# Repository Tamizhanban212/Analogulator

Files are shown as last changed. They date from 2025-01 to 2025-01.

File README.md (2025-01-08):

# Analogulator

In an era dominated by digital computation, analog computing remains relevant for specific applications that require real-time processing, low power consumption, and continuous data handling. Unlike digital calculators that rely on discrete logic and binary arithmetic, analog calculators use continuous voltage or current levels to represent data, enabling faster and more efficient computations for certain tasks.

This project, "Analog Calculator," aims to design a calculator using only analog components (e.g., op-amps, MOSFETs, resistors, capacitors) to perform mathematical operations such as addition, subtraction, multiplication, division, and advanced functions like integration and differentiation. By leveraging analog circuits, this project explores a simpler, more efficient approach to computations in specific real-world scenarios.

Hence, we have designed PCB for the analog calculator inside a 11 cm x 11 cm frame and you can see the final product shown below.

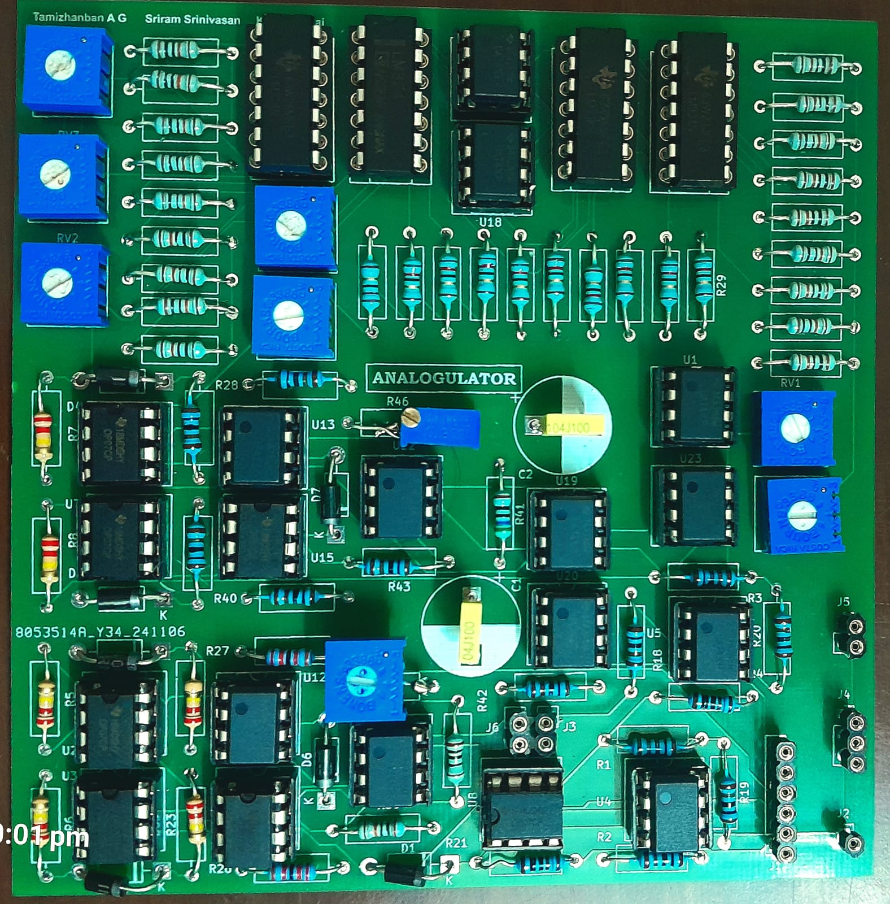
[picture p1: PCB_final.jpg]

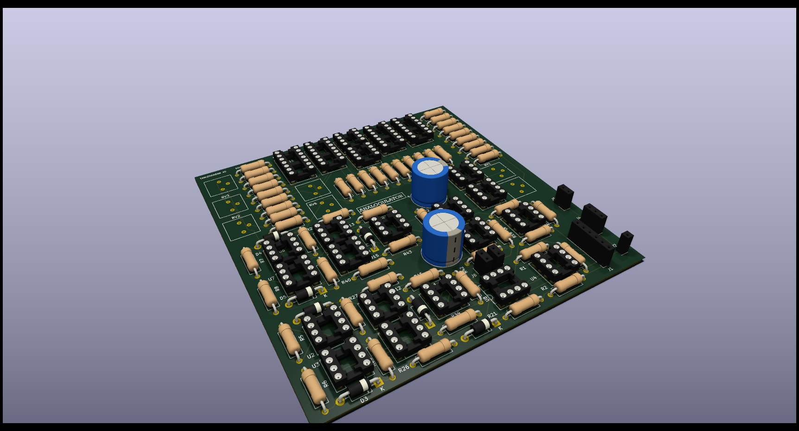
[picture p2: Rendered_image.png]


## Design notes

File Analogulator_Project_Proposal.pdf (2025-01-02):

Analog and Mixed Signal Circuits | Analogulator - Project Proposal

# Analog and Mixed Signal Circuits

### Project Proposal

Analogulator: Redefining Calculations with an Analog Twist

## Introduction

In an era dominated by digital computation, analog computing remains relevant for specific applications that require real-time processing, low power consumption, and continuous data handling. Unlike digital calculators that rely on discrete logic and binary arithmetic, analog calculators use continuous voltage or current levels to represent data, enabling faster and more efficient computations for certain tasks. This project, "Analog Calculator," aims to design a calculator using only analog components (e.g., op-amps, MOSFETs, resistors, capacitors) to perform mathematical operations such as addition, subtraction, multiplication, division, and advanced functions like integration and differentiation. In fact, operational amplifiers originally got its name due to their ability to perform arithmetic operations. Thus, by leveraging analog circuits, this project explores a simpler, more efficient approach to computations in specific real-world scenarios.

## Problem Statement

The renewed interest in analog computing highlights its significance in contemporary technology, particularly for tasks that demand intensive processing such as signal processing, image processing and waveform generation. A key limitation of digital computing lies in its time complexity and power consumption when handling non-discrete calculations such as integration and differentiation. While digital systems offer precise calculations, many applications prioritize speed and low power consumption over extreme precision, where accuracy to 15 decimal places is unnecessary.

Analog computing excels in solving differential equations and generating waveforms—tasks that are inherently challenging for digital systems. This capability is driving advancements in hybrid architectures, enhancing domains like artificial intelligence, embedded systems, and control systems, where fast and energy-efficient computations are vital.

[1] Leading integrated circuit manufacturers are adopting similar strategies, using analog front ends to capitalize on their speed, followed by digital processing for improved accuracy. In successive approximation analog-to-digital converters (ADCs), for instance, reaching a solution typically requires multiple steps. However, by starting with an approximate value provided by the analog front end, the number of steps— and thus computation time and power consumption—can be significantly reduced.
| [1]

## Proposed Approach

### Overview of Approach

The proposed approach involves designing an analog calculator using only analog components like op-amps, MOSFETs, resistors, and capacitors. The calculator will perform a range of mathematical operations, from basic arithmetic (addition, subtraction, multiplication, division and roots) to advanced functions (integration and differentiation). The system will use voltage-based inputs to select operands and operations and employ analog storage techniques for intermediate results. The output will be displayed using LEDs in case of simple operations and an oscilloscope for integration and differentiation. Each component of the system will be built as a modular block, tested independently, and integrated into a cohesive unit.

### Components and Blocks

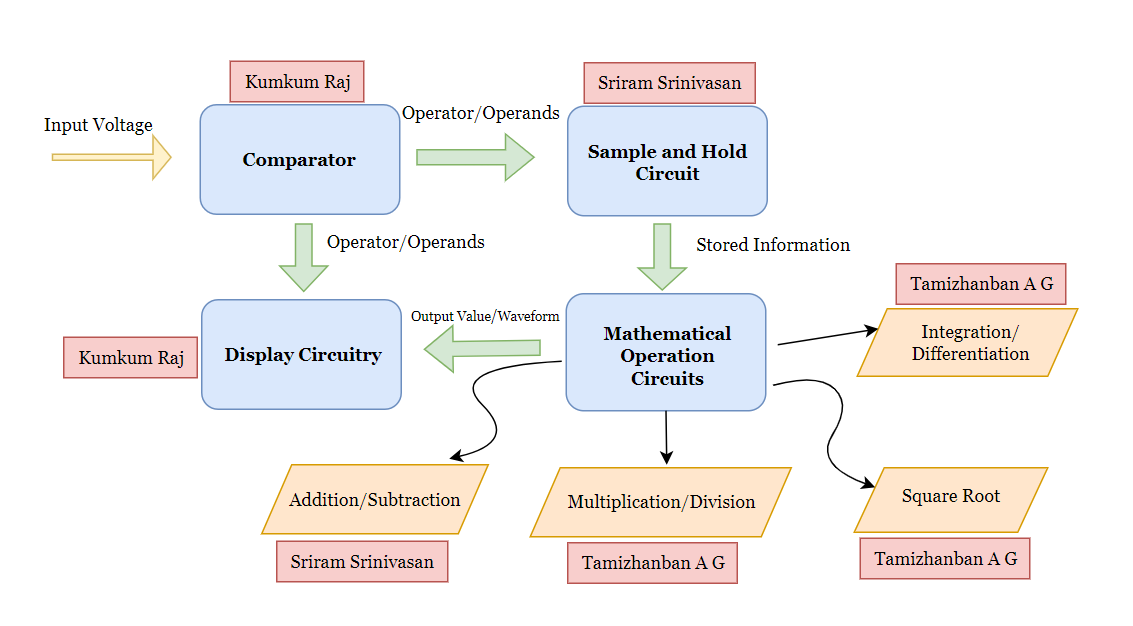
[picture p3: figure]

### 1. Input Signal Selection: AC or DC Voltage?

For this project, a DC input voltage is the most suitable choice. The objective is to vary the input signal in real-time and observe the corresponding number on an array of LEDs. Using a DC signal allows each voltage level to be mapped directly to a specific digit without the complexities associated with AC signals, such as synchronization with the waveform's phase or frequency. But in the case of integration and differentiation, any signal can be given as input to get a waveform in the output.

### 2. Comparator - Voltage to Digit/Operator Conversion

Multiple window comparator circuits, built using ICs like the LM393 or op-amps such as the LM741 or LM358, can be used to compare the input voltage against predefined reference voltages corresponding to different digits or operators (e.g., 0-1V for "0", 1-2V for "1", etc.). Each comparator triggers when the input voltage falls within its specific range, converting the analog voltage to a digit or an operator.

### 3. Sample and Hold Circuits with Push Button

Sample and Hold (S/H) circuits capture and maintain voltages for operands and operators. The input voltage can be adjusted to select a digit or operator shown by LEDs, then press a push button to store this voltage via a

MOSFET switch. Releasing the button isolates the capacitor, and an op-amp buffer stabilizes the voltage. Three S/H circuits store Operand 1, Operator, and Operand 2 until needed. [2]

### 4. Analog Circuits for Mathematical Operations

- Addition/Subtraction: Operational amplifiers (op-amps) like the LM741 or TL081 can be configured as summing amplifiers for addition and differential amplifiers for subtraction.
- Multiplication/Division: Analog circuits can be built using multipliers ICs such as the AD633. This IC can handle both multiplication and division.
- Square Root: A possible approach would be to use an analog multiplier (MC1495 or AD633) as a squaring circuit, in the feedback loop of an op-amp. [3]
- Integration/Differentiation: Achieved with integrator/differentiator circuits using op-amps like the LM324 or TL081 and carefully chosen resistors and capacitors.

### 5. Display Circuitry Using LEDs and Oscilloscope

For the basic operations (addition, subtraction, multiplication, division), LEDs can be used to display the digits and operators based on the comparator applied on the voltage. For integration and differentiation, an oscilloscope displays the output waveform, showing changes over time. LCDs may be used for clearer representation if needed.

## Advantages of the Proposed Approach

- Low Power Consumption: By leveraging analog components, the proposed solution consumes significantly less power compared to digital counterparts, making it suitable for battery-operated or lowpower applications.
- Real-Time Computation: Analog circuits provide near-instantaneous responses due to their continuous nature, which is beneficial for applications requiring real-time processing without the delay of digital conversions.
- Reduced Complexity and Cost: Analog circuits can perform complex operations with fewer components and simpler designs compared to digital circuits that require complex processing units and memory.
- Elimination of Digital Noise: The analog approach is inherently less prone to digital noise and quantization errors, which enhances accuracy in certain contexts.

## References

[1] R. Elliott, “Analogue electronics maths functions,” Elliott Sound Products. [Online]. Available: https://sound-au.com/articles/maths-functions.htm#intro.

[2] “Sample and Hold Circuit,” GeeksforGeeks. [Online]. Available: https://www.geeksforgeeks.org/sampleand-hold-circuit/. (https://www.geeksforgeeks.org/sample-and-hold-circuit/)
[3] M. Angelo, "Extracting the square root of a voltage," Electronics Stack Exchange, https://electronics.stackexchange.com/questions/78294/extracting-the-square-root-of-a-voltage

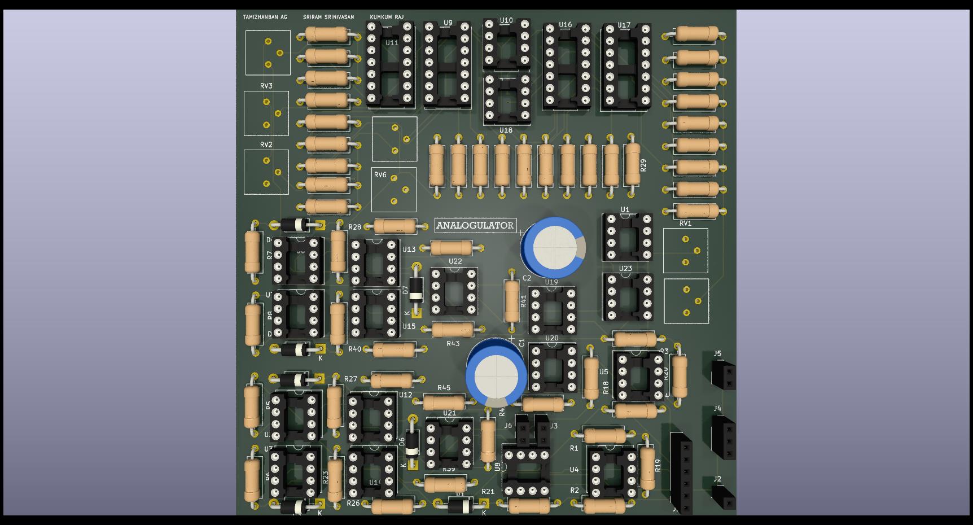
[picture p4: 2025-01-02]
analogulator.jpg

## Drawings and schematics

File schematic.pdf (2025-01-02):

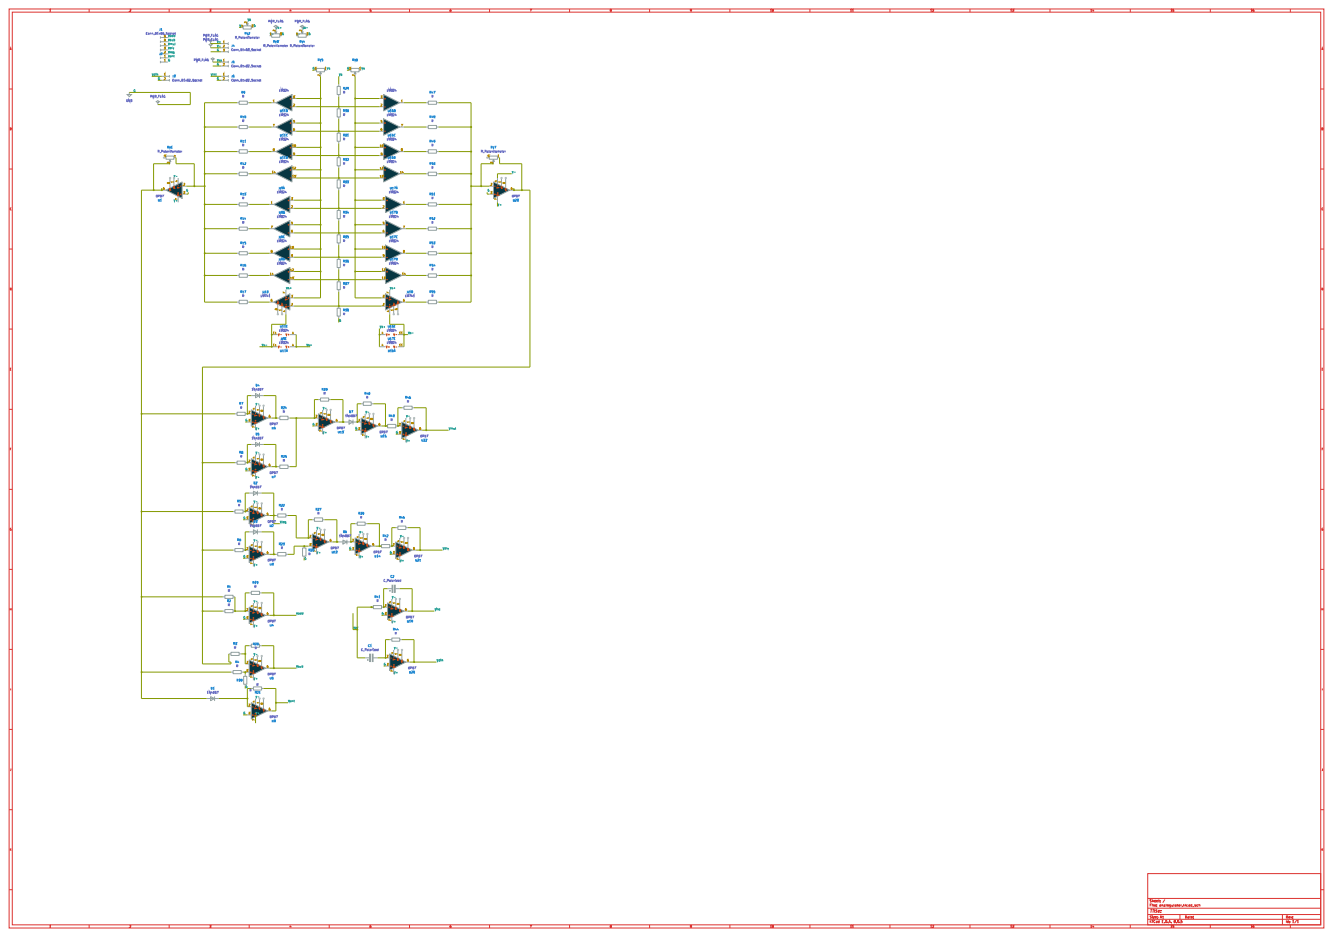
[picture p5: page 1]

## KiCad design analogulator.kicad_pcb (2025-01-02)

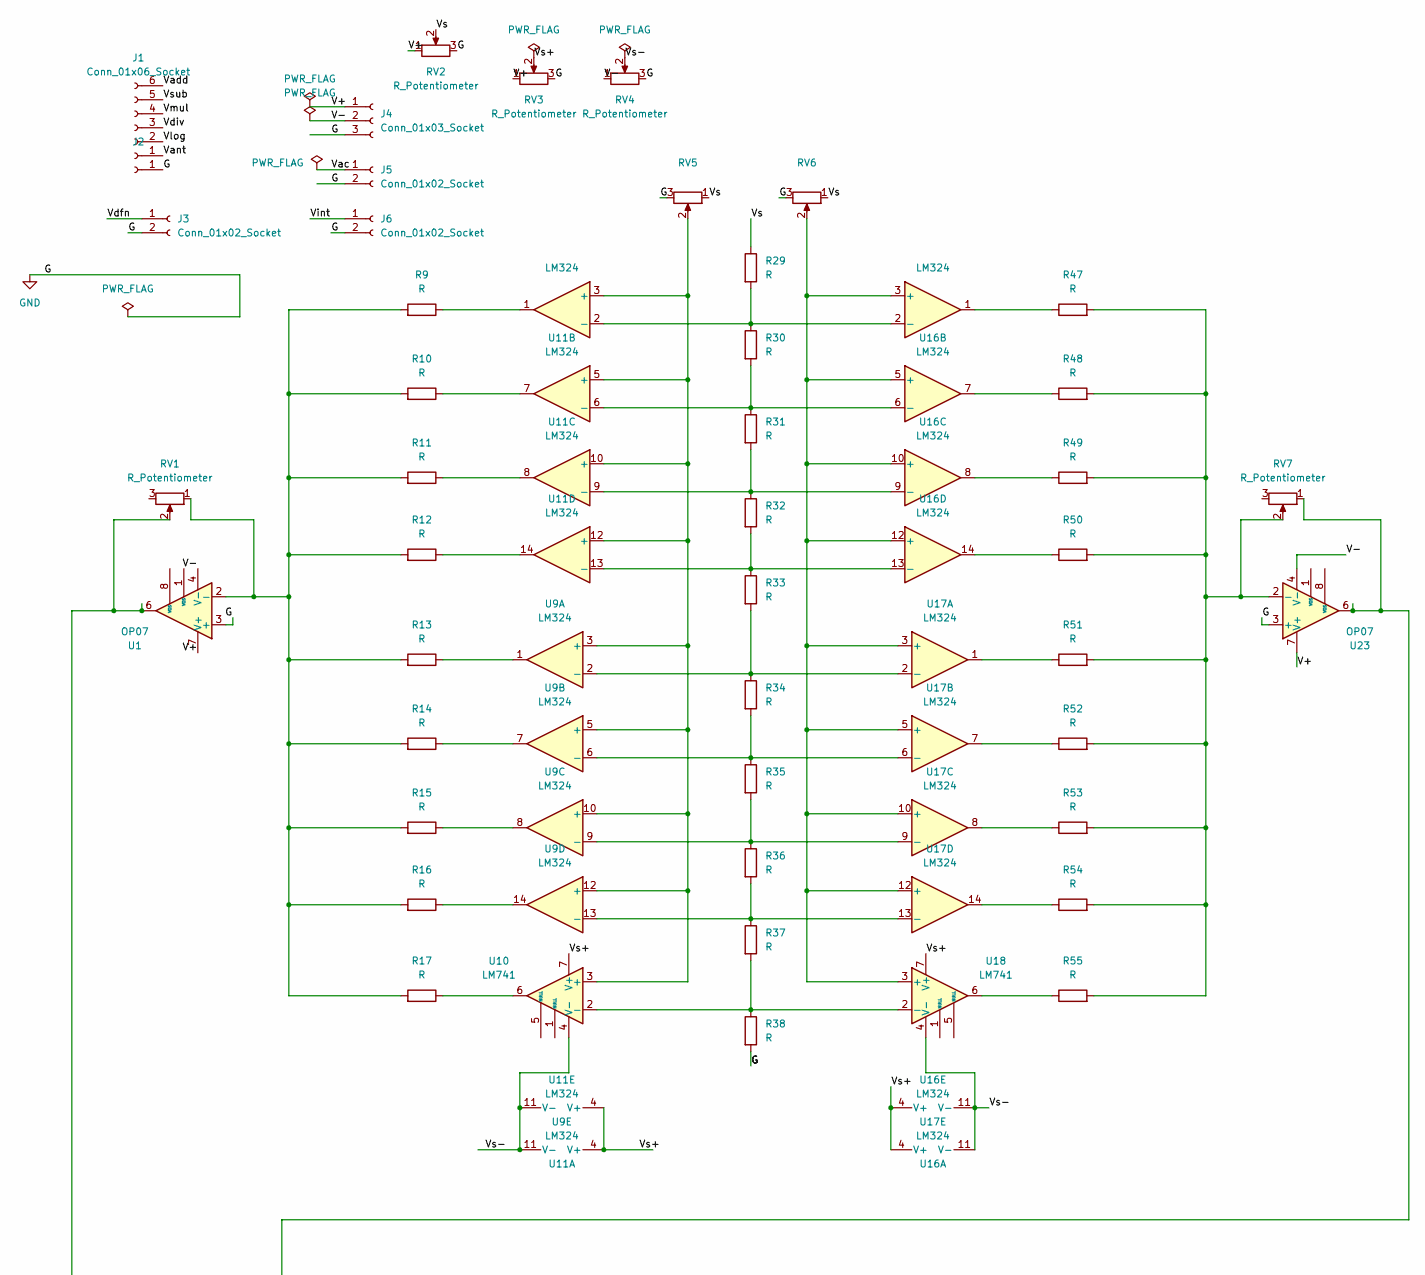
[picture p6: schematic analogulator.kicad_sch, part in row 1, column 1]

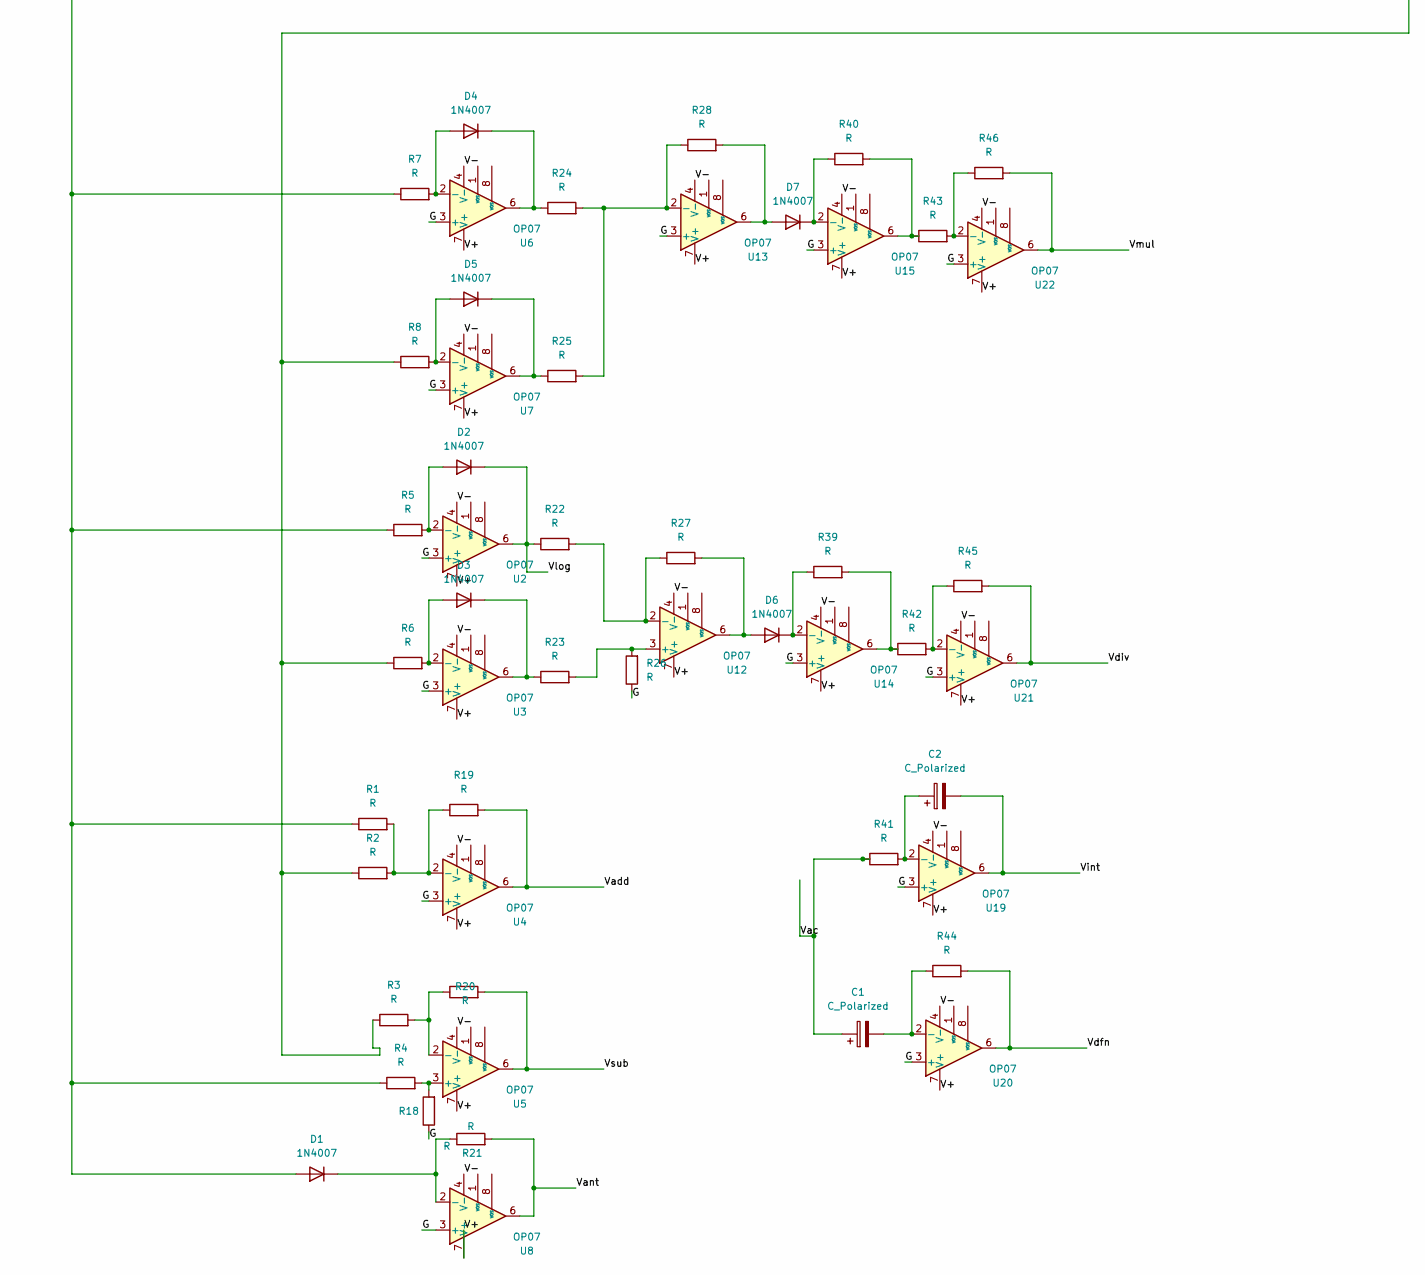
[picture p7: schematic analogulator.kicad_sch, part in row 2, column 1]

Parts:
C1, C2: C_Polarized; CP_Radial_D12.5mm_P7.50mm
D1, D2, D3, D4, D5, D6, D7: 1N4007; D_DO-41_SOD81_P10.16mm_Horizontal
J1: Conn_01x06_Socket; PinSocket_1x06_P2.54mm_Vertical
J2: Conn_01x01_Socket; PinSocket_1x01_P2.54mm_Vertical
J3, J5, J6: Conn_01x02_Socket; PinSocket_1x02_P2.54mm_Vertical
J4: Conn_01x03_Socket; PinSocket_1x03_P2.54mm_Horizontal
R1, R2, R3, R4, R5, R6, R7, R8, R9, R10, R11, R12, R13, R14, R15, R16, R17, R18, R19, R20, R21, R22, R23, R24, R25, R26, R27, R28, R29, R30, R31, R32, R33, R34, R35, R36, R37, R38, R39, R40, R41, R42, R43, R44, R45, R46, R47, R48, R49, R50, R51, R52, R53, R54, R55: R; R_Axial_DIN0309_L9.0mm_D3.2mm_P12.70mm_Horizontal
RV1, RV2, RV3, RV4, RV5, RV6, RV7: R_Potentiometer; Potentiometer_Bourns_3386P_Vertical
U1, U2, U3, U4, U5, U6, U7, U8, U12, U13, U14, U15, U19, U20, U21, U22, U23: OP07; DIP-8_W7.62mm_Socket
U9, U11, U16, U17: LM324; DIP-14_W7.62mm_Socket
U10, U18: LM741; DIP-8_W7.62mm_Socket

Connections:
/V+: J4.1, RV2.1, RV3.1, U1.7 (V+), U2.7 (V+), U3.7 (V+), U4.7 (V+), U5.7 (V+), U6.7 (V+), U7.7 (V+), U8.7 (V+), U12.7 (V+), U13.7 (V+), U14.7 (V+), U15.7 (V+), U19.7 (V+), U20.7 (V+), U21.7 (V+), U22.7 (V+), U23.7 (V+)
/V-: J4.2, RV4.1, U1.4 (V-), U2.4 (V-), U3.4 (V-), U4.4 (V-), U5.4 (V-), U6.4 (V-), U7.4 (V-), U8.4 (V-), U12.4 (V-), U13.4 (V-), U14.4 (V-), U15.4 (V-), U19.4 (V-), U20.4 (V-), U21.4 (V-), U22.4 (V-), U23.4 (V-)
/Vac: C1.1, J5.1, R41.1
/Vadd: J1.6, R19.2, U4.6
/Vant: J1.1, R21.2, U8.6
/Vdfn: J3.1, R44.2, U20.6
/Vdiv: J1.3, R45.2, U21.6
/Vint: C2.2, J6.1, U19.6
/Vlog: D2.1 (K), J1.2, R22.1, U2.6
/Vmul: J1.4, R46.2, U22.6
/Vs: R29.1, RV2.2, RV5.1, RV6.1
/Vs+: RV3.2, U9.4 (V+), U10.7 (V+), U11.4 (V+), U16.4 (V+), U17.4 (V+), U18.7 (V+)
/Vs-: RV4.2, U9.11 (V-), U10.4 (V-), U11.11 (V-), U16.11 (V-), U17.11 (V-), U18.4 (V-)
/Vsub: J1.5, R20.2, U5.6
GND: J2.1, J3.2, J4.3, J5.2, J6.2, R18.1, R26.1, R38.2, RV2.3, RV3.3, RV4.3, RV5.3, RV6.3, U1.3 (+), U2.3 (+), U3.3 (+), U4.3 (+), U6.3 (+), U7.3 (+), U8.3 (+), U13.3 (+), U14.3 (+), U15.3 (+), U19.3 (+), U20.3 (+), U21.3 (+), U22.3 (+), U23.3 (+)
unnamed: D1.2 (A), R1.1, R4.1, R5.1, R7.1, RV1.2, U1.6
unnamed: D1.1 (K), R21.1, U8.2 (-)
unnamed: D2.2 (A), R5.2, U2.2 (-)
unnamed: D3.2 (A), R6.2, U3.2 (-)
unnamed: D3.1 (K), R23.1, U3.6
unnamed: D4.2 (A), R7.2, U6.2 (-)
unnamed: D4.1 (K), R24.1, U6.6
unnamed: D5.2 (A), R8.2, U7.2 (-)
unnamed: D5.1 (K), R25.1, U7.6
unnamed: D6.2 (A), R27.2, U12.6
unnamed: D6.1 (K), R39.1, U14.2 (-)
unnamed: D7.2 (A), R28.2, U13.6
unnamed: D7.1 (K), R40.1, U15.2 (-)
unnamed: R2.1, R3.1, R6.1, R8.1, RV7.1, U23.6
unnamed: R9.1, U11.1
unnamed: R10.1, U11.7
unnamed: R11.1, U11.8
unnamed: R12.1, U11.14
unnamed: R13.1, U9.1
unnamed: R14.1, U9.7
unnamed: R15.1, U9.8
unnamed: R16.1, U9.14
unnamed: R17.1, U10.6
unnamed: R39.2, R42.1, U14.6
unnamed: R40.2, R43.1, U15.6
unnamed: R47.1, U16.1
unnamed: R48.1, U16.7
unnamed: R49.1, U16.8
unnamed: R50.1, U16.14
unnamed: R51.1, U17.1
unnamed: R52.1, U17.7
unnamed: R53.1, U17.8
unnamed: R54.1, U17.14
unnamed: R55.1, U18.6
unnamed: R9.2, R10.2, R11.2, R12.2, R13.2, R14.2, R15.2, R16.2, R17.2, RV1.1, U1.2 (-)
unnamed: R1.2, R2.2, R19.1, U4.2 (-)
unnamed: R4.2, R18.2, U5.3 (+)
unnamed: R3.2, R20.1, U5.2 (-)
unnamed: RV5.2, U9.3 (+), U9.5 (+), U9.10 (+), U9.12 (+), U10.3 (+), U11.3 (+), U11.5 (+), U11.10 (+), U11.12 (+)
unnamed: R37.2, R38.1, U10.2 (-), U18.2 (-)
unnamed: R29.2, R30.1, U11.2 (-), U16.2 (-)
unnamed: R30.2, R31.1, U11.6 (-), U16.6 (-)
unnamed: R31.2, R32.1, U11.9 (-), U16.9 (-)
unnamed: R32.2, R33.1, U11.13 (-), U16.13 (-)
unnamed: R23.2, R26.2, U12.3 (+)
unnamed: R22.2, R27.1, U12.2 (-)
unnamed: R24.2, R25.2, R28.1, U13.2 (-)
unnamed: RV6.2, U16.3 (+), U16.5 (+), U16.10 (+), U16.12 (+), U17.3 (+), U17.5 (+), U17.10 (+), U17.12 (+), U18.3 (+)
unnamed: R33.2, R34.1, U9.2 (-), U17.2 (-)
unnamed: R34.2, R35.1, U9.6 (-), U17.6 (-)
unnamed: R35.2, R36.1, U9.9 (-), U17.9 (-)
unnamed: R36.2, R37.1, U9.13 (-), U17.13 (-)
unnamed: C2.1, R41.2, U19.2 (-)
unnamed: C1.2, R44.1, U20.2 (-)
unnamed: R42.2, R45.1, U21.2 (-)
unnamed: R43.2, R46.1, U22.2 (-)
unnamed: R47.2, R48.2, R49.2, R50.2, R51.2, R52.2, R53.2, R54.2, R55.2, RV7.2, U23.2 (-)

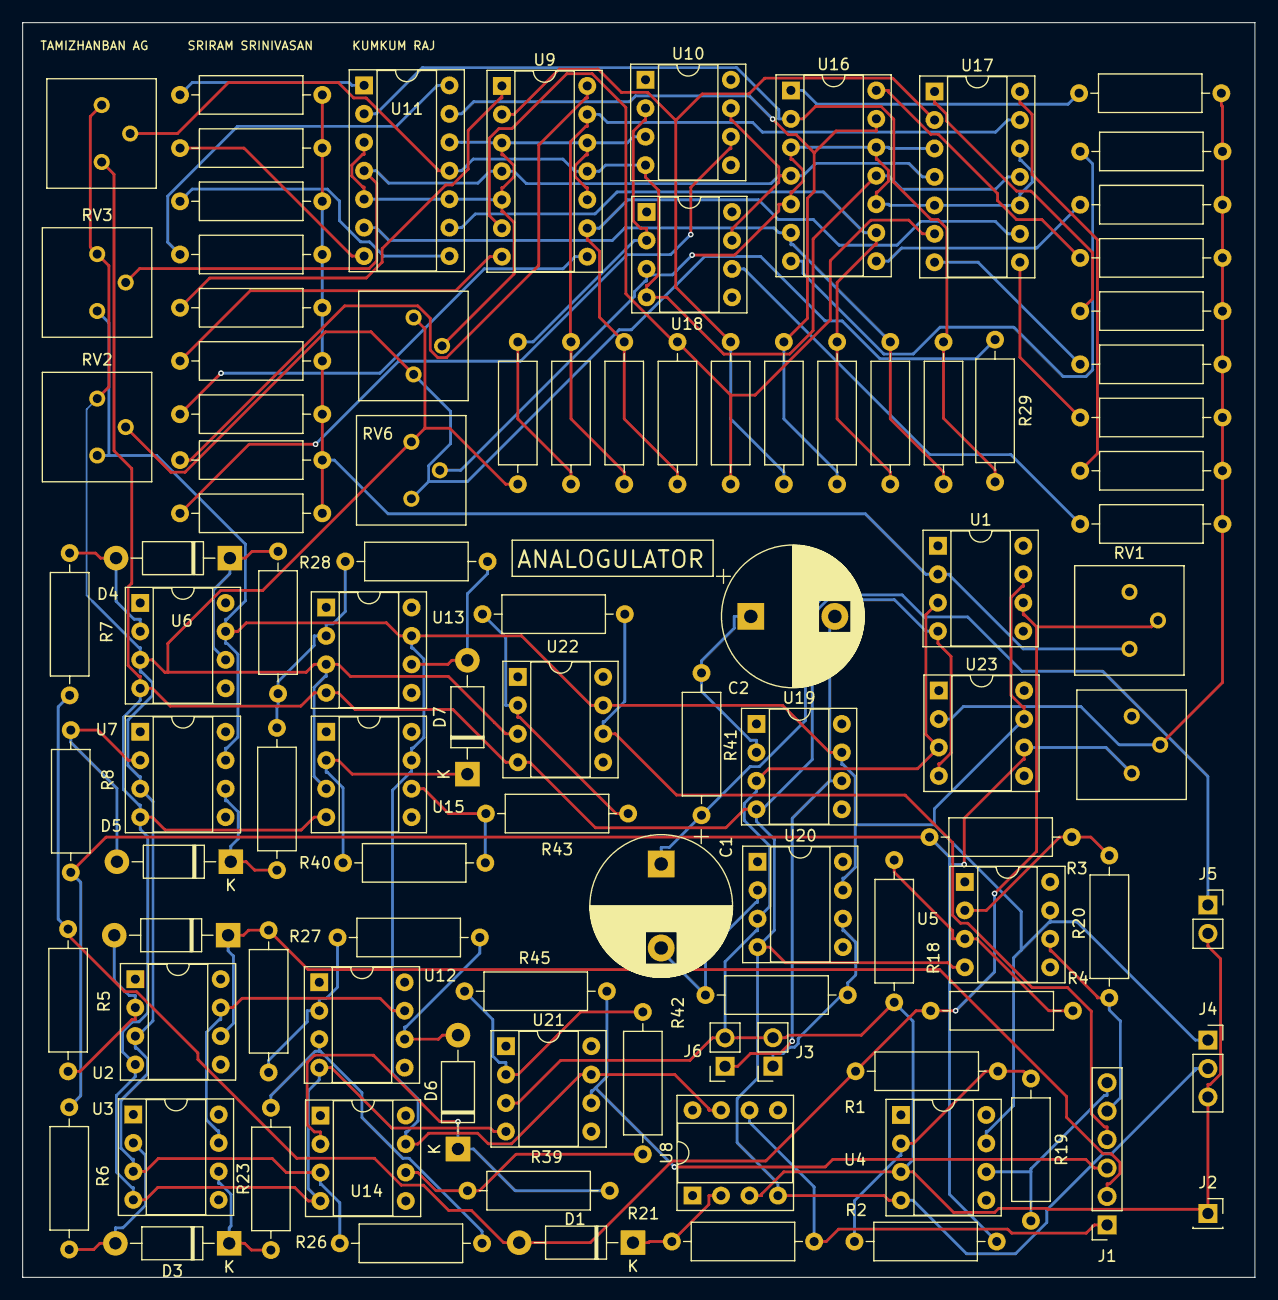
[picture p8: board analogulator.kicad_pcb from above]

Board: 2 copper layers, 110.0 x 112.0 mm, 100 parts (0 on the bottom side), 72 nets.
